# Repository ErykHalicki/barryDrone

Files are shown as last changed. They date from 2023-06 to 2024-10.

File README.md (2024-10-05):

# BARRY Aerial Drone
Aim of this project is to build a drone from scratch, then later use the platform to test autonomous functionality

Currently still on early testing, but I plan on using the platform to learn more about ROS and computer vision.

[Flight Test](https://youtube.com/shorts/YYaDXmu7loY?feature=share)

[Original Attempt](https://github.com/Stargor14/Stone-Drone)

## Topics: Computer Vision, PID Control, ROS, wireless communication

Custom 3d Printed frame, raspi zero W for processing, esp32 for flight control, [rs2205 motors](https://www.aliexpress.com/item/1005001270601236.html?spm=a2g0o.order_list.order_list_main.122.6ecf1802ioyX7h) and included escs

Using ps3 controller with [sixaxispairer](https://github.com/user-none/sixaxispairer) and [esp32-ps3](https://github.com/jvpernis/esp32-ps3) for flight testing

If i had the funding id love to explore the possibility of an autonomous drone swarm

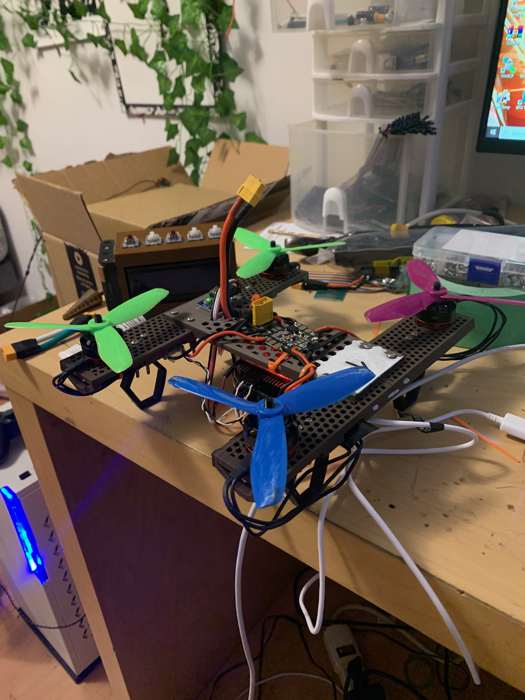
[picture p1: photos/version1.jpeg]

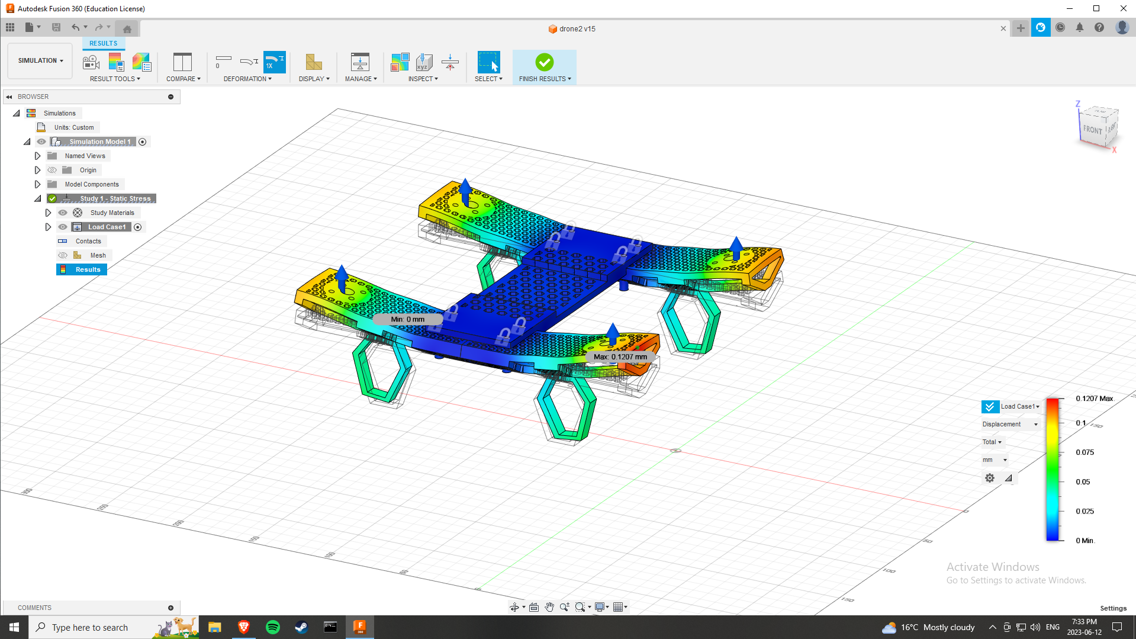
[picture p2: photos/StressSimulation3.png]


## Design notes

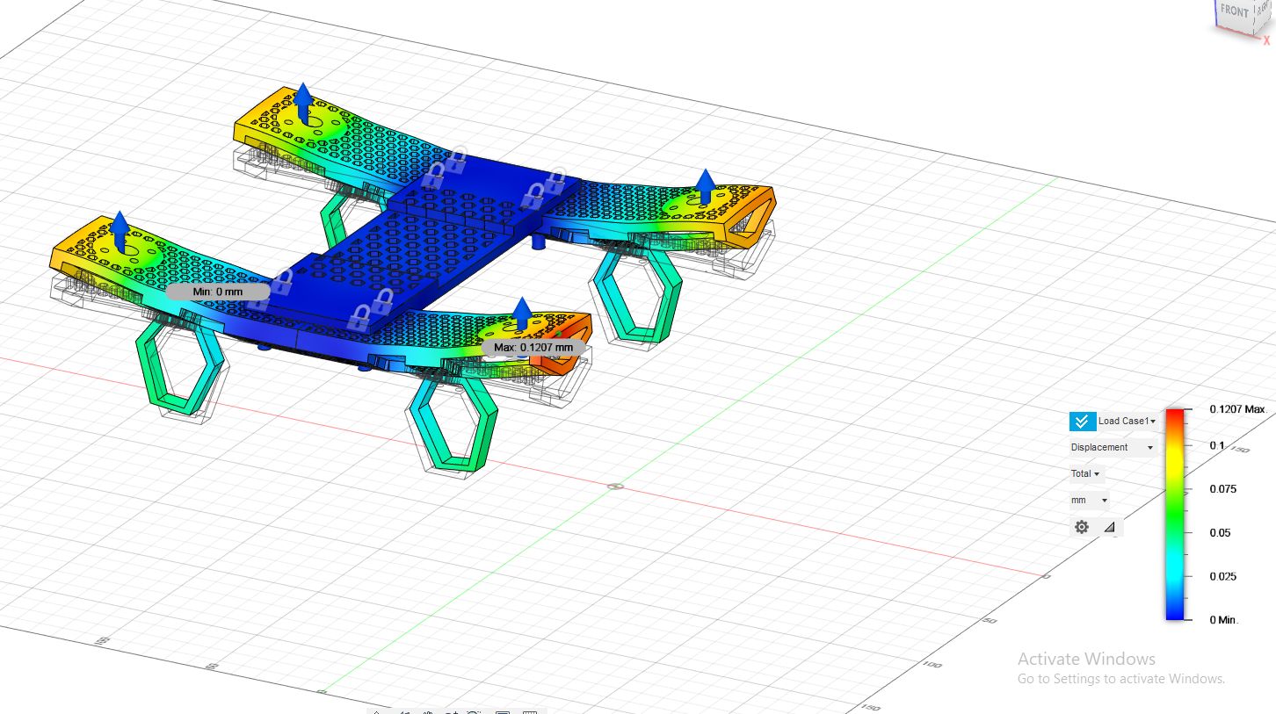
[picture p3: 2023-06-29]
photos/StressSimulation2.png

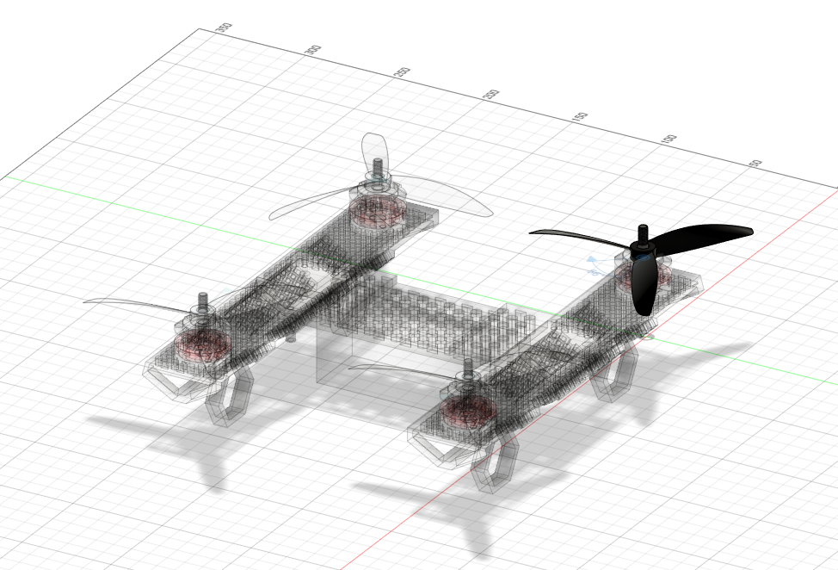
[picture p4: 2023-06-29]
photos/frameVersion2.png

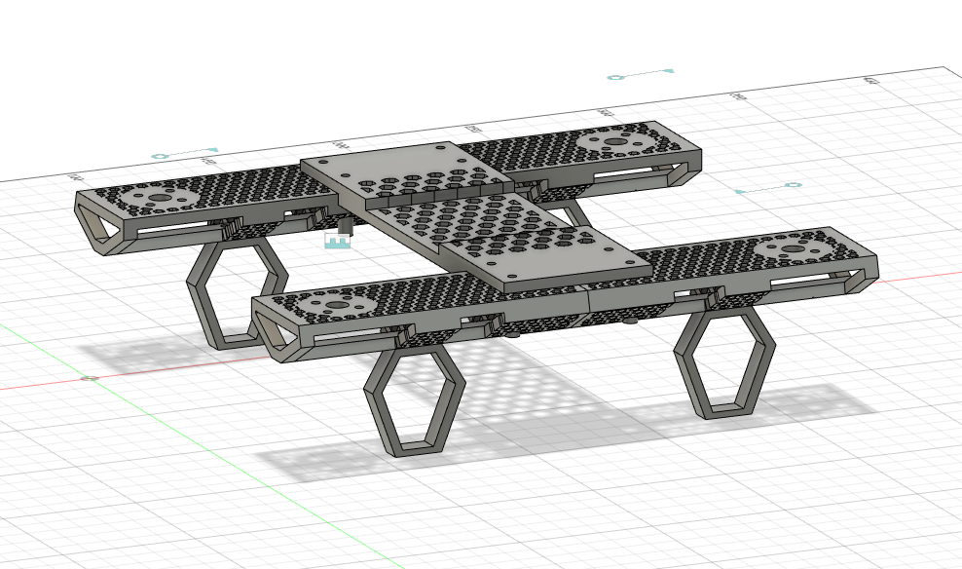
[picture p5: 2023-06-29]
photos/frameV2-2.png

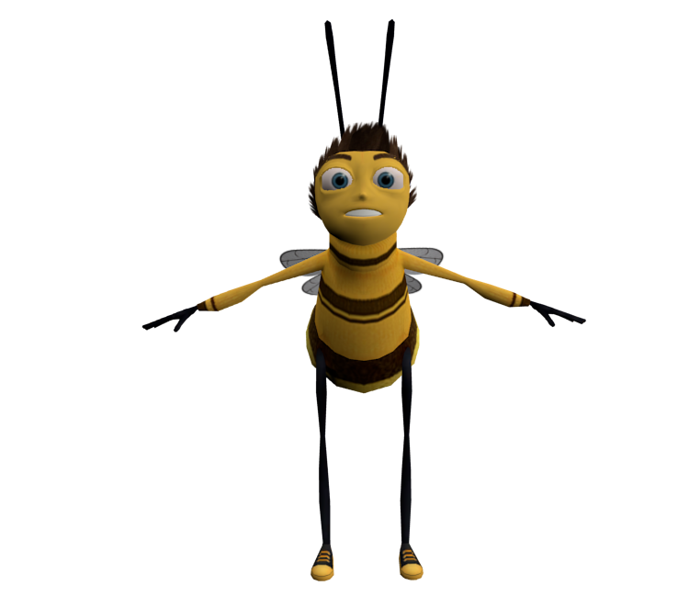
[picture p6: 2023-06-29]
barry.png

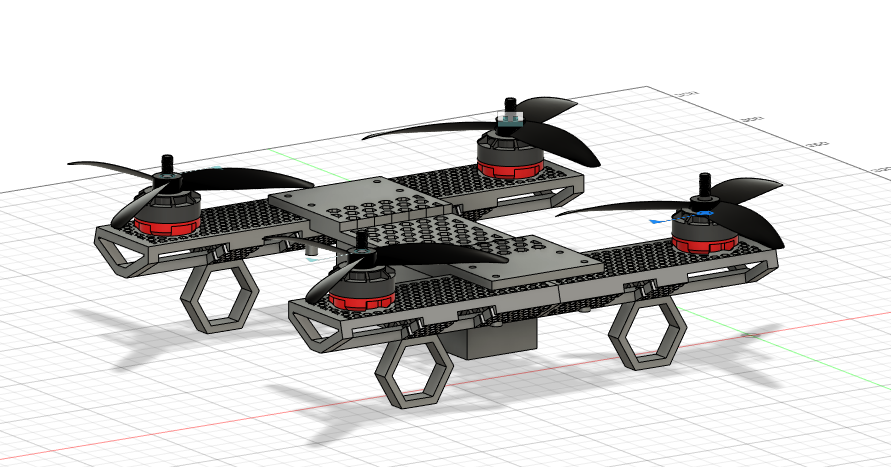
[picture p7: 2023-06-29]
photos/frameV2_1.png

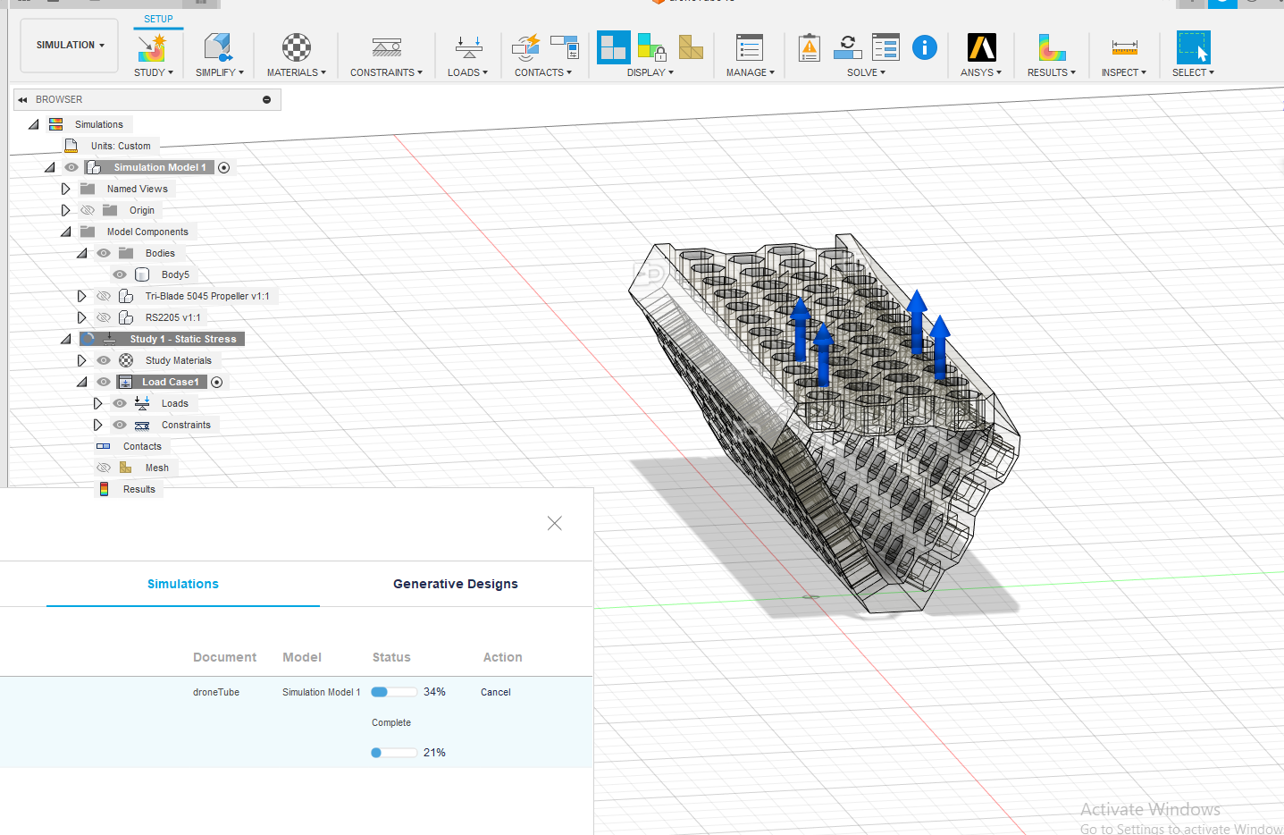
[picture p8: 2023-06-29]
photos/StressSimulation1.png

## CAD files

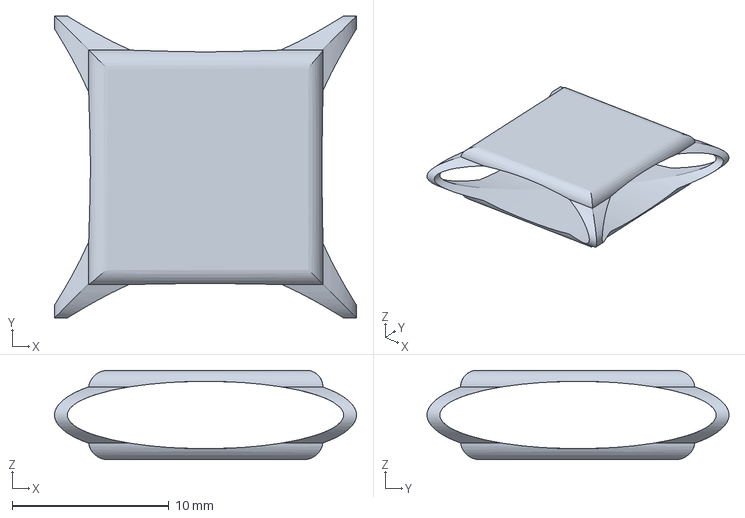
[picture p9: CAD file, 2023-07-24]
3dmodels/IMU_Dampnerv2.3mf
19.3 x 19.3 x 5.70 mm

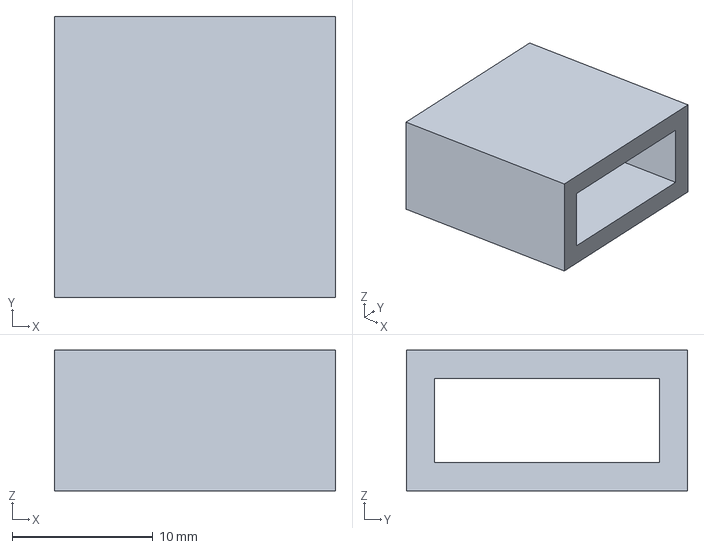
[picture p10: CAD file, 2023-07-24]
3dmodels/drone dampner.3mf
20.0 x 20.0 x 10.0 mm

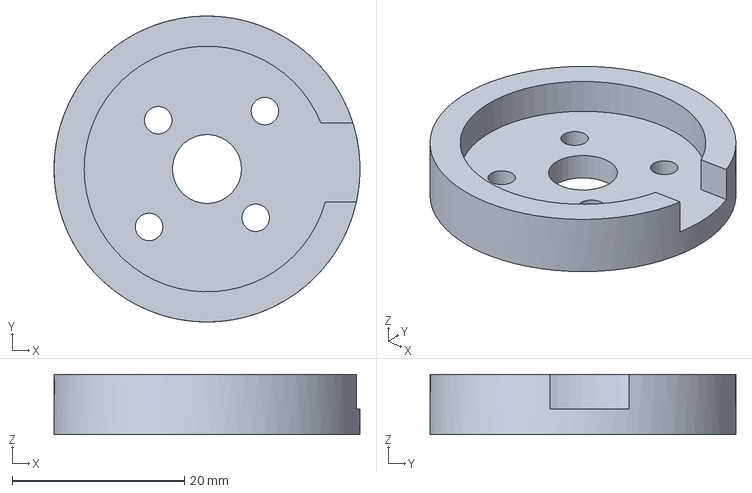
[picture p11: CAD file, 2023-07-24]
3dmodels/motor dampner.3mf
35.5 x 35.5 x 7.00 mm

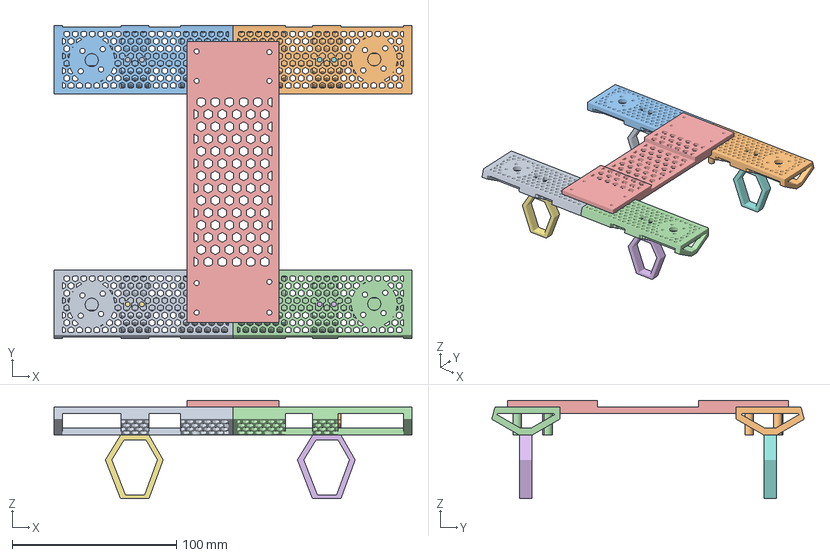
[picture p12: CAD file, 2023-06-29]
3dmodels/drone2 v16.3mf
218.2 x 190.5 x 59.9 mm

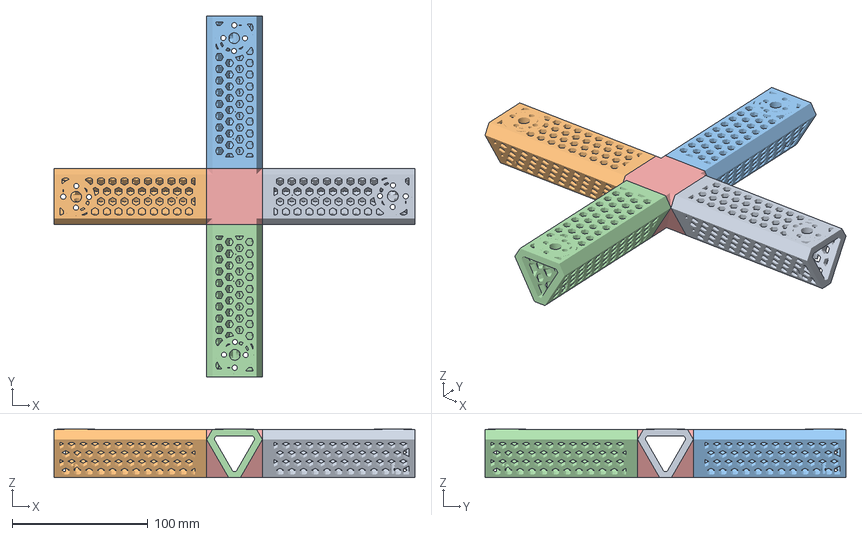
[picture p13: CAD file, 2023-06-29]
3dmodels/droneTube v6.3mf
266.3 x 266.3 x 35.8 mm

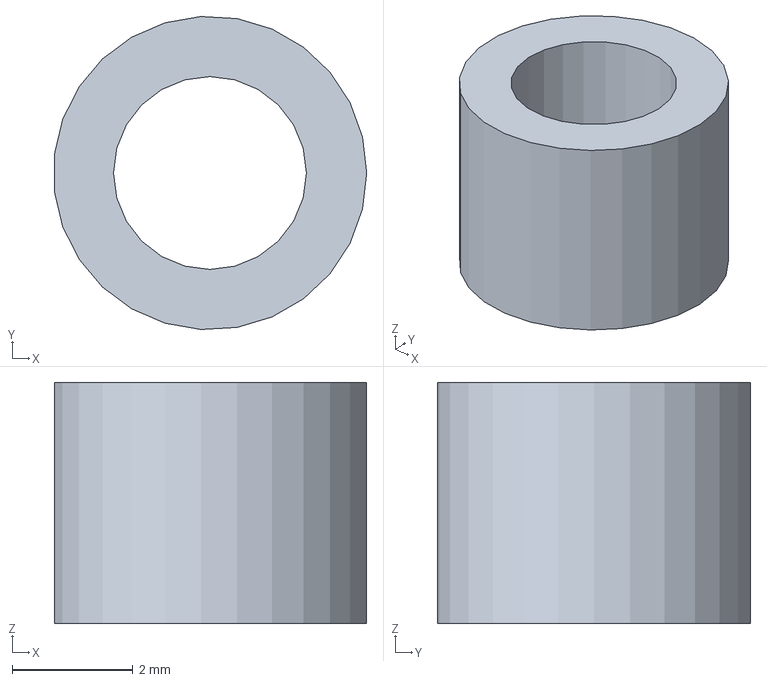
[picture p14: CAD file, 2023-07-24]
3dmodels/screw spacer.3mf
5.18 x 5.19 x 4.00 mm

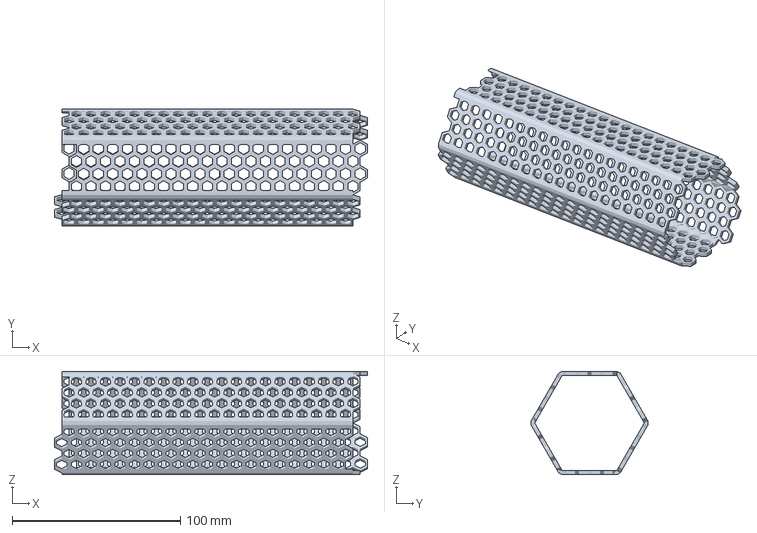
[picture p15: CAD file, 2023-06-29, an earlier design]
3dmodels/droneTube v2.3mf
185.8 x 69.5 x 61.3 mm

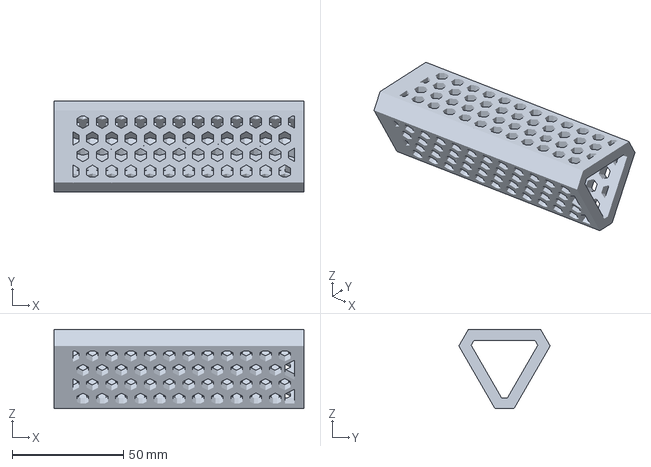
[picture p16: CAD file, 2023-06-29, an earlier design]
3dmodels/droneTube v4.3mf
112.6 x 41.2 x 35.7 mm

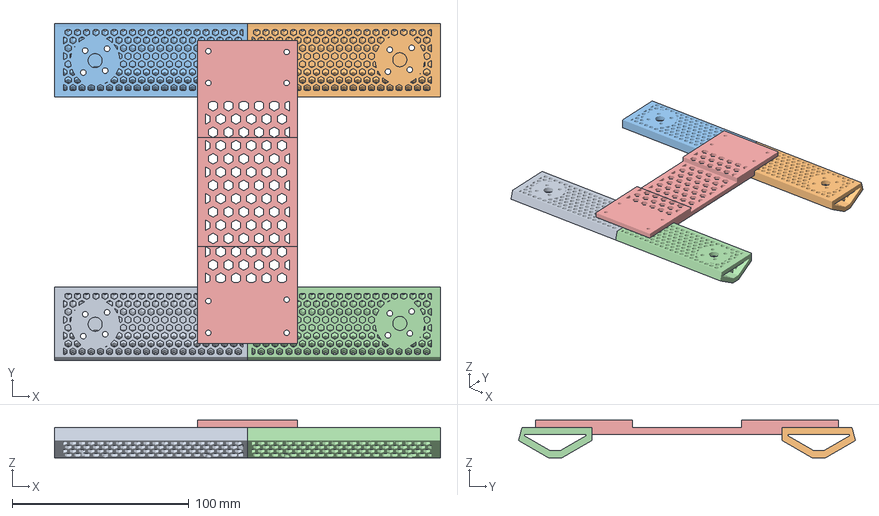
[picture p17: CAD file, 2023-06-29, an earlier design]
3dmodels/drone2 v8.3mf
218.2 x 190.5 x 21.2 mm

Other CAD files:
3dmodels/drone2 v15.3mf

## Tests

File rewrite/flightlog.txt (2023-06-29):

FLIGHT 1: July 28 9:12 PM

absolute fail, test with rotors failed after inexplainable software crash caused 100% power on 2 rotors,
leading to a sideways flip, destroying the frame

F2 IMPROVEMENTS:
full firmware rewrite, incremental PID testing, new frame arms printed from PETG

FLIGHT 2: TBD

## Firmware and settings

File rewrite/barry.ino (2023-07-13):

#include<esp_now.h>
#include <Ps3Controller.h>
#include <WiFi.h>
#include <Wire.h>
//Signal: 14,25,16,18 Pull down: 32,26,5

extern int16_t accZero[3];
extern float yawRate;
extern float rollPitchRate;
extern float P_PID;
extern float I_PID;
extern float D_PID;
extern float P_Level_PID;
extern float I_Level_PID;
extern float D_Level_PID;


float PID[3]={0,0,0};
enum ang { ROLL,PITCH,YAW };
enum channels { THR,PIT,RUD,ROL };
static int16_t gyroADC[3];
static int16_t accADC[3];
static int16_t gyroData[3];
static float angle[2] = {0,0};  
extern int calibratingA;
static int rcValue[8];
static int16_t rcCommand[] = {0,0,0};

#define ACCRESO 4096
#define CALSTEPS 256 // gyro and acc calibration steps
#define MINTHROTTLE 1100
#define MIDRUD 1500
uint8_t destAddress[6];

volatile boolean recv;
static uint16_t servo[4];
const int MotPin0 = 25;  //BR
const int MotPin1 = 14;  //FR
const int MotPin2 = 18;  //BL
const int MotPin3 = 16;  //FL
const int MotChannel0 = 2;
const int MotChannel1 = 3;   
const int MotChannel2 = 4;
const int MotChannel3 = 5;
const int safety = 1300;

const bool using_espnow=false;
struct ControllerData {
  bool calibrating,cross;
  bool tri;
  bool sqr;
  bool circ;
  bool leftTrigger;
  bool rightTrigger;
  bool leftShoulder;
  bool rightShoulder;
  int leftStickX;
  int leftStickY;
  int rightStickX;
  int rightStickY;
  float gyroXOffset;
  float gyroYOffset;
  float gyroX;
  float gyroY;
 };

ControllerData cData;

void writeServo() 
{
  ledcWrite(MotChannel0, uint16_t(min(safety,int(servo[0]))));
  ledcWrite(MotChannel1, uint16_t(min(safety,int(servo[1]))));
  ledcWrite(MotChannel2, uint16_t(min(safety,int(servo[2]))));
  ledcWrite(MotChannel3, uint16_t(min(safety,int(servo[3]))));
}

void initServo() 
{
  ledcSetup(MotChannel0, 500, 11); // 500 hz PWM, 11-bit resolution
  ledcSetup(MotChannel1, 500, 11); // 500 hz PWM, 11-bit resolution
  ledcSetup(MotChannel2, 500, 11); // 500 hz PWM, 11-bit resolution
  ledcSetup(MotChannel3, 500, 11); // 500 hz PWM, 11-bit resolution
  ledcAttachPin(MotPin0, MotChannel0); 
  ledcAttachPin(MotPin1, MotChannel1); 
  ledcAttachPin(MotPin2, MotChannel2); 
  ledcAttachPin(MotPin3, MotChannel3); 
}

void mix(){
  if (rcValue[THR] > MINTHROTTLE){
    servo[0] = constrain(rcValue[THR] - PID[ROLL] + PID[PITCH] - PID[YAW],1000,2000);
	servo[1] = constrain(rcValue[THR] - PID[ROLL] - PID[PITCH] + PID[YAW],1000,2000);
    servo[2] = constrain(rcValue[THR] + PID[ROLL] + PID[PITCH] + PID[YAW],1000,2000);
    servo[3] = constrain(rcValue[THR] + PID[ROLL] - PID[PITCH] - PID[YAW],1000,2000);
  }
  else 
  { 
    PID[0] = 0; PID[1] = 0; PID[2] = 0;
    servo[0] = 1000; servo[1] = 1000; servo[2] = 1000; servo[3] = 1000;
  }
}
void setup(){
	Serial.begin(9600);
	Serial.println("BARRY Startup...");
	if(!using_espnow){
		Ps3.begin();
		Ps3.attach(update);
		Ps3.attachOnConnect(onConnect);
	}
	else{
		WiFi.mode(WIFI_MODE_STA);
  		Serial.println(WiFi.macAddress());
		esp_now_init();
		esp_now_register_recv_cb(receiveControllerData);
	}
	delay(3000); // give it some time to stop shaking after battery plugin
  	MPU6050_init();
  	MPU6050_readId(); // must be 0x68, 104dec
	pinMode(32, INPUT_PULLDOWN);  
	pinMode(26, INPUT_PULLDOWN);  
	pinMode(5, INPUT_PULLDOWN);  
  	delay(500); 
  	initServo();
}
void loop(){
	pid();
	rcValue[THR]=map(max(0,cData.leftStickY),0,127,1000,1800);
	rcValue[RUD]=map(cData.leftStickX,-127,127,1000,2000);
	rcValue[ROL]=map(cData.rightStickX,-127,127,1000,2000);
	rcValue[PIT]=map(cData.rightStickY,-127,127,1000,2000);

	Serial.print(angle[0]);
	Serial.print(" ");
	Serial.println(angle[1]);
}

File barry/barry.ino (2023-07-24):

#include <esp_now.h>
#include <Ps3Controller.h>
#include <WiFi.h>
#include <Wire.h>
#include <EEPROM.h>
#include "MPU6050_light.h"
#include "encoding.h"

#define WIFI_CHANNEL 4
//#define espnow

extern float P_Gyro;
extern float I_Gyro;
extern float D_Gyro;
extern float P_Angle;
extern float I_Angle;
extern float D_Angle;

#define ACCRESO 4096
#define CYCLETIME 10
#define MINTHROTTLE 1100
#define MIDRUD 1500
#define THRCORR 0

enum ang { ROLL,PITCH,YAW };

static int16_t gyroADC[3];
static int16_t accADC[3];
static int16_t gyroData[3];
static float angle[2]    = {0,0};  
extern int calibratingA;

long lastUpdate;
#define ROL 0
#define PIT 1
#define THR 2
#define RUD 3

static int16_t rcCommand[] = {0,0,0};
static int16_t rcValue[4];  // in us, center = 1500
#define GYRO     0
#define STABI    1
static int8_t flightmode;
static int8_t oldflightmode;

boolean armed = false;
uint8_t armct = 0;
int debugvalue = 0;
MPU6050 mpu(Wire);

void setup(){
  	Serial.begin(9600); Serial.println();
	delay(3000); // give it some time to stop shaking after battery plugin
	Wire.begin();
	byte status = mpu.begin();
	while(status!=0){
		Serial.println("MPU6050 Failed to start, trying again");
		delay(1000);
		status = mpu.begin();
	}
	Serial.println(F("Calculating offsets, do not move MPU6050"));
  	delay(1000);
  	mpu.calcOffsets(true,true); // gyro and accelero
	Serial.println("MPU6050 Success");

	#ifdef espnow 
		WiFi.mode(WIFI_STA);
  		Serial.println(WiFi.macAddress());
		esp_now_init();
		esp_now_register_recv_cb(receiveControllerData);
	#else
		Ps3.begin();
		Ps3.attach(update);
		Ps3.attachOnConnect(onConnect);
	#endif

  	//EEPROM.begin(64);
  	//if (EEPROM.read(62) != 0xAA) Serial.println("Need to check and write PID");
  	//else PID_Read(); // eeprom is initialized

	//Signal: 14,25,16,18 Pull down: 32,26,5
	pinMode(32, INPUT_PULLDOWN);  
	pinMode(26, INPUT_PULLDOWN);  
	pinMode(5, INPUT_PULLDOWN);  
  	delay(500); 
  	initServo();
}

uint32_t rxt; // receive time, used for falisave

void loop(){
  	uint32_t now,mnow,diff; 
  	now = millis(); // actual time
  	if (debugvalue == 5) mnow = micros();
  	if (millis()-lastUpdate<100){
    	buf_to_rc();
    	if (debugvalue == 4) Serial.printf("%4d %4d %4d %4d \n", rcValue[0], rcValue[1], rcValue[2], rcValue[3]); 
    	if (armed) {
      		rcValue[THR]    -= THRCORR;
      		rcCommand[ROLL]  = rcValue[ROL] - MIDRUD;
      		rcCommand[PITCH] = rcValue[PIT] - MIDRUD;
      		rcCommand[YAW]   = rcValue[RUD] - MIDRUD;
    	}  
    	else{  
      		if (rcValue[THR] < MINTHROTTLE) armct++;
      		if (armct >= 25)armed = true;
    	}
    	rxt = millis();
	}

  	pid();
	mix();
	mpu.update();
  	writeServo();
		//printOutputs();	
  	// Failsave part
  	if (now > rxt+90){
		//future self land emergency fuction
    	rcValue[THR] = MINTHROTTLE*1.2;
    	rxt = now;
  	}
  	delay(CYCLETIME-1);  

  	if (debugvalue == 5){
    	diff = micros() - mnow;
    	Serial.println(diff); 
  	}
}

int readsernum(){
  int num;
  char numStr[3]; 
  numStr[0] = Serial.read();
  numStr[1] = Serial.read();
  return atol(numStr);
}

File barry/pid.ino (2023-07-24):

static int16_t axisPID[3];
float lastError[3] = {0, 0, 0};
float P_Gyro = 0.9;    // P8
float I_Gyro = 0.00;   // I8
float D_Gyro = 0.05;   // D8

float P_Angle = 0.5;  // P8
float I_Angle = 0.001; // I8
float D_Angle = 0.05;   // D8
float overallScale = 0.4; // PID output multiplier
float errorSum[3] = {0, 0, 0};
#define maxYawRate 180
#define maxTiltAngle 35
#define IMU_FILTER_SIZE 15 // Size of the filter window
float angleX=0,angleY=0,gyroZ=0;
float imuReadings[IMU_FILTER_SIZE][3];

void pid() {
  int16_t P, I, D;
  float error;

  // Update IMU readings and apply KZ filter
  for (int i = IMU_FILTER_SIZE - 1; i > 0; i--) {
    for (int j = 0; j < 3; j++) {
      imuReadings[i][j] = imuReadings[i - 1][j];
    }
  }
  imuReadings[0][0] = mpu.getAngleY();
  imuReadings[0][1] = mpu.getAngleX();
  imuReadings[0][2] = mpu.getGyroZ();

  // Apply KZ filter
  for (int j = 0; j < 3; j++) {
    float filteredValue = 0;
    for (int i = 0; i < IMU_FILTER_SIZE; i++) {
      filteredValue += imuReadings[i][j];
    }
    filteredValue /= IMU_FILTER_SIZE;
    // Use the filtered value for angle and gyro
    if (j==0) angleX = angleX*0.95+filteredValue*0.05;
    if (j==1) angleY = angleY*0.95+filteredValue*0.05;
    if (j==2) gyroZ = gyroZ*0.95+filteredValue*0.05;
  }

	//angleY-= max(0,(int)map(rcValue[THR],1300,1400,15,25));	

  // Roll control
  error = map(angleX, -maxTiltAngle, maxTiltAngle, -300, 300) - rcCommand[ROLL];
  errorSum[0] += error;
  P = error * P_Angle;
  I = errorSum[0] * I_Angle;
  D = (error - lastError[0]) * D_Angle;
  axisPID[0] = (P + I + D) * overallScale;
  lastError[0] = error;

  // Pitch control
  error = map(-angleY, -maxTiltAngle, maxTiltAngle, -300, 300) - rcCommand[PITCH];
  errorSum[1] += error;
  P = error * P_Angle;
  I = errorSum[1] * I_Angle;
  D = (error - lastError[1]) * D_Angle;
  axisPID[1] = (P + I + D) * overallScale;
  lastError[1] = error;

  // Yaw control
  error = map(-gyroZ, -maxYawRate, maxYawRate, -300,300) - rcCommand[YAW];
  P = error * P_Gyro;
  I = errorSum[2] * I_Gyro; // Note: There's no I term for Yaw in the original code
  D = (error - lastError[2]) * D_Gyro;
  axisPID[2] = (P + I + D) * overallScale;
  lastError[2] = error;

  // Output PID values for debugging
  Serial.print(axisPID[0]);
  Serial.print(" ");
  Serial.print(axisPID[1]);
  Serial.print(" ");
  Serial.println(axisPID[2]);
/*
	Serial.print(angleX);
  Serial.print(" ");
  Serial.print(angleY);
  Serial.print(" ");
  Serial.println(gyroZ);

*/
}
/*
static int16_t axisPID[3];
float lastError[]={0,0,0};
float P_Gyro = 0.9;    // P8
float I_Gyro = 0.00;    // I8
float D_Gyro = 0.05;    // D8

//0.8 0.01 0.5 a little shaky, on the edge
//0.8 0.01 0.9 a little shaky, good to fly

float P_Angle = 0.40;   // P8
float I_Angle = 0.001;  // I8
float D_Angle = 0.3;   // D8
float overallScale = 0.2; // PID output multiplier
float errorSum[]={0,0,0};
#define maxYawRate 180
#define maxTiltAngle 35
#define IMAX 10000
float angleY=0,angleX=0,gyroZ=0;
//pid tuning?
//check if vibration is still a big issue
//print covers for the proppellors
//get esp now data reporting working <--- very important
void pid(){
	int16_t P,I,D;
	float error;
	//roll=y pitch=x yaw=z
	angleY=0.95*angleY+mpu.getAngleY()*0.05;
	error=map(angleY,-maxTiltAngle,maxTiltAngle,-500,500)-rcCommand[ROLL];//adjust
	errorSum[ROLL]+=error;
	P=error*P_Angle;
	I=max(IMAX,errorSum[ROLL])*I_Angle;
	D=(error-lastError[ROLL])*D_Angle;	
	axisPID[ROLL]=(P+I+D)*overallScale;
	lastError[ROLL]=error;

	angleX=0.95*angleX+mpu.getAngleX()*0.05;
	error=map(-angleX,-maxTiltAngle,maxTiltAngle,-500,500)-rcCommand[PITCH];//adjust
	errorSum[PITCH]+=error;
	P=error*P_Angle;
	I=max(IMAX,errorSum[PITCH])*I_Angle;
	D=(error-lastError[PITCH])*D_Angle;	
	axisPID[PITCH]=(P+I+D)*overallScale;
	lastError[PITCH]=error;
	
	gyroZ=gyroZ*0.95+mpu.getGyroZ()*0.05;
	error=map(-gyroZ,-maxYawRate,maxYawRate,-500,500)-rcCommand[YAW];//adjust
	//errorSum[YAW]+=error;
	P=error*P_Gyro;
	I=max(IMAX,errorSum[YAW])*I_Gyro;//0 value for now
	D=(error-lastError[YAW])*D_Gyro;	
	axisPID[YAW]=(P+I+D)*overallScale;
	lastError[YAW]=error;
	Serial.print(axisPID[ROLL]);
	Serial.print(" ");
	Serial.print(axisPID[PITCH]);
	Serial.print(" ");
	Serial.print(axisPID[YAW]);
	Serial.print(" ");
	Serial.print(errorSum[ROLL]);
	Serial.print(" ");
	Serial.print(errorSum[PITCH]);
	Serial.print(" ");
	Serial.println(errorSum[YAW]);
}
*/

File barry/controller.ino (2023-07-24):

bool calibrating,cross,tri,sqr,circ,leftTrigger,rightTrigger, leftShoulder, rightShoulder;

bool outputVal=false;
int leftStickX,leftStickY,rightStickX,rightStickY, calibrationCountdown=5;
float gyroXOffset=0,gyroYOffset=0,gyroX,gyroY;

void calibrateGyro(){
	calibrating=true;
	Serial.println("~~~~~~PLACE CONTROLLER ON FLAT SURFACE~~~~~~");
	delay(1000);
	Serial.println("Calibrating in: ");
	for(int i=calibrationCountdown;i>0;i--){
		Serial.println(i);
		delay(1000);
	}
	for(int i=0;i<10;i++){
		gyroXOffset+=Ps3.data.sensor.accelerometer.x;
		gyroYOffset+=Ps3.data.sensor.accelerometer.y;
		delay(10);
	}
	gyroXOffset/=10;
	gyroYOffset/=10;
	calibrating=false;
}

void update(){

	lastUpdate=millis();
	if(!calibrating){
		if( Ps3.event.button_down.cross )cross=true;
		if( Ps3.event.button_up.cross )cross=false;
	
	    if( Ps3.event.button_down.square )sqr=true;
	    if( Ps3.event.button_up.square )sqr=false;
	
	    if( Ps3.event.button_down.triangle )tri=true;
	    if( Ps3.event.button_up.triangle )tri=false;
	
	    if( Ps3.event.button_down.circle )circ=true;
	    if( Ps3.event.button_up.circle )circ=false;
		leftShoulder=false;
		if(Ps3.data.analog.button.l1>0)leftShoulder=true;
		rightShoulder=false;
		if(Ps3.data.analog.button.r1>0)rightShoulder=true;
		leftTrigger=false;
		if(Ps3.data.analog.button.l2>0)leftTrigger=true;
		rightTrigger=false;
		if(Ps3.data.analog.button.r2>0)rightTrigger=true;
	
	
	    leftStickX=Ps3.data.analog.stick.lx;
	   	leftStickY=-Ps3.data.analog.stick.ly;
	
	   	rightStickX=Ps3.data.analog.stick.rx;
		rightStickY=-Ps3.data.analog.stick.ry;
		gyroX+=Ps3.data.sensor.accelerometer.x-gyroXOffset;
		gyroY+=Ps3.data.sensor.accelerometer.y-gyroYOffset;
		gyroX/=2;
		gyroY/=2;
	}
}
void outputController(){
	Serial.print("L1: ");
	Serial.print(leftShoulder);
	Serial.print("R1: ");
	Serial.print(rightShoulder);
	Serial.print("L2: ");
	Serial.print(leftTrigger);
	Serial.print("R2: ");
	Serial.print(rightTrigger);
	Serial.print("X: ");
	Serial.print(cross);
	Serial.print(" O: ");
	Serial.print(circ);
	Serial.print(" T: ");
	Serial.print(tri);
	Serial.print(" S: ");
	Serial.print(sqr);
	Serial.print(" LX: ");
	Serial.print(leftStickX);
	Serial.print(" LY: ");
	Serial.print(leftStickY);
	Serial.print(" RX: ");
	Serial.print(rightStickX);
	Serial.print(" RY: ");
	Serial.print(rightStickY);	
	Serial.print(" X: ");
	Serial.print(gyroX);
	Serial.print(" Y: ");
	Serial.println(gyroY);
}
void onConnect(){
	Serial.println("Connected");
	String address = Ps3.getAddress();
    Serial.println("Started receiving on: "+address);
}

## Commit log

2023-06-29 uploaded all work
    [drone2 v15.3mf, drone2 v16.3mf, drone2 v8.3mf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]
2023-07-15 starting pid rewrite
2023-07-24 KZ filter and pid rewrite
    [IMU_Dampnerv2.3mf, drone dampner.3mf, motor dampner.3mf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]
